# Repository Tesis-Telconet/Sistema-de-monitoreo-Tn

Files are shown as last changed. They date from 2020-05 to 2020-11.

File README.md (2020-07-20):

# Sistema-de-Monitoreo

Este repositorio contiene material diverso para poner en marcha un sistema de monitoreo de amenazas físicas (temperatura, humedad, voltajes, corrientes, calidad de gas). Los datos son recopilados por los distintos tipos de sensores instalados, el proceso de los datos y el envio de información es realizado por las placas Arduino UNO, la información es almacenada en una base de datos SQL. Los datos pueden ser visualizados en un sitio web, este sitio fue desarrollado usando la plantilla ADMIN LTE, para la comunicación entre los Arduinos y la base de datos y / o la base de datos y el sitio web, se desarrollo una APREST escrita en Python que utiliza el framework FLASK.  

El contenido se organiza del siguiente modo:

CASES: diseño delos cases para los Arduinos

Diagramas Proteus: Diagramas de conexión entre sensores y placas Arduino UNO

apirest2: Códigos para la creación de la APIREST y el desarrollo del sitio WEB

codigos finales: Códigos para las placas Arduinos UNO

Planos: Imágenes de las áreas donde se instaló el sistema y el plano del sistema en las instalaciones de Telconet

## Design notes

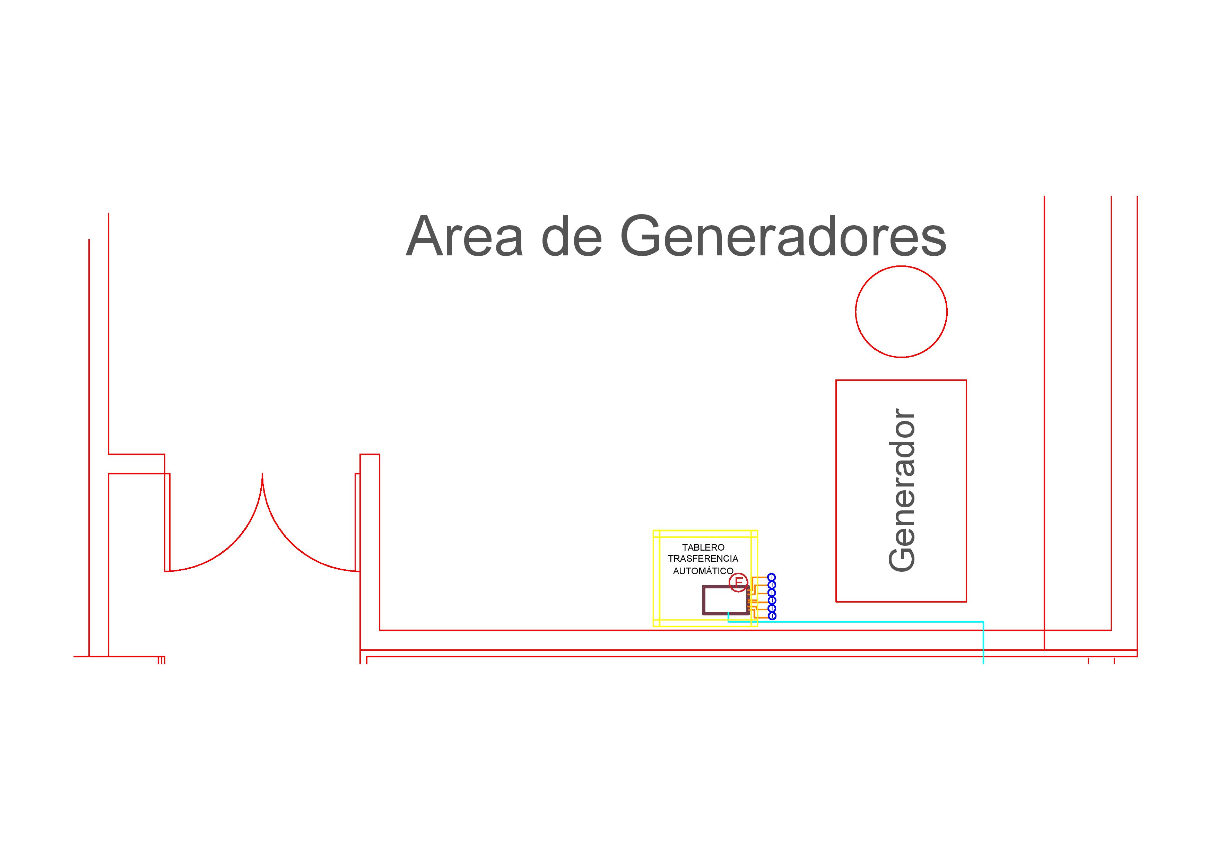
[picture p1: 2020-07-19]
planos/Plano Area Generador.jpg

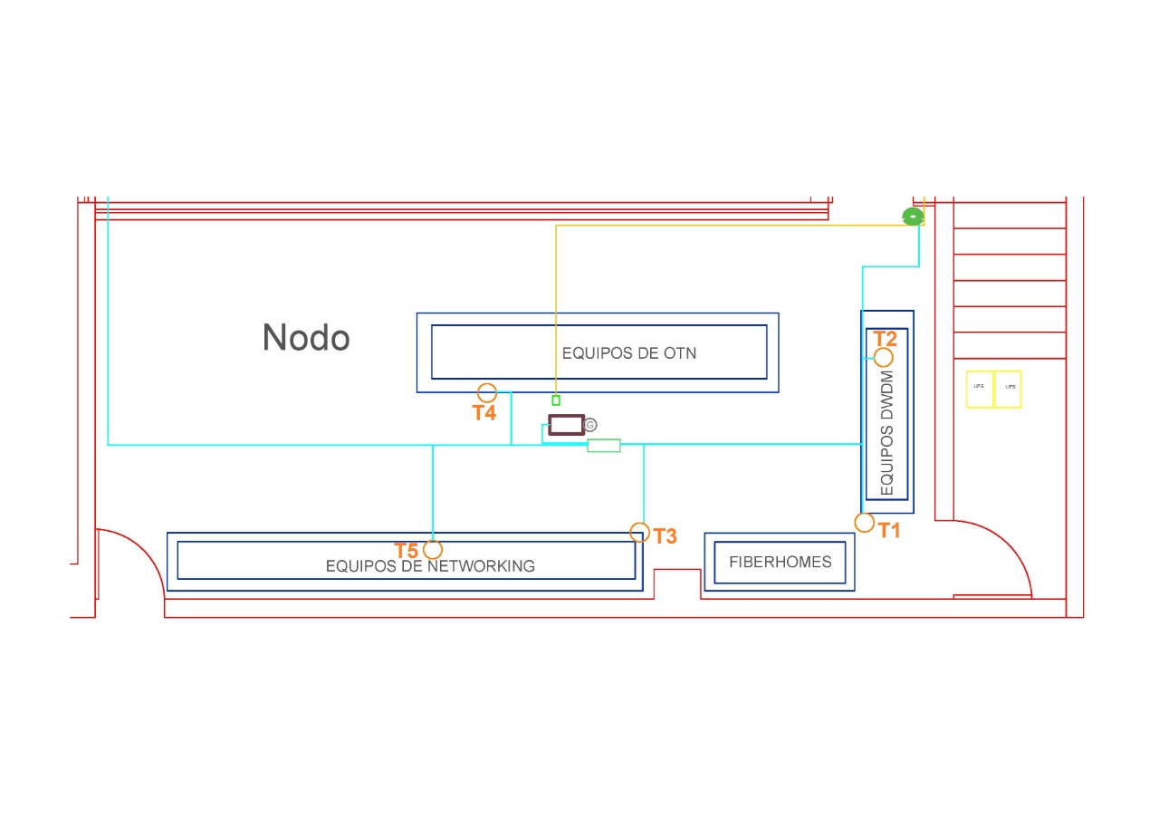
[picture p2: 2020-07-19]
planos/Plano nodo gosseal.jpeg

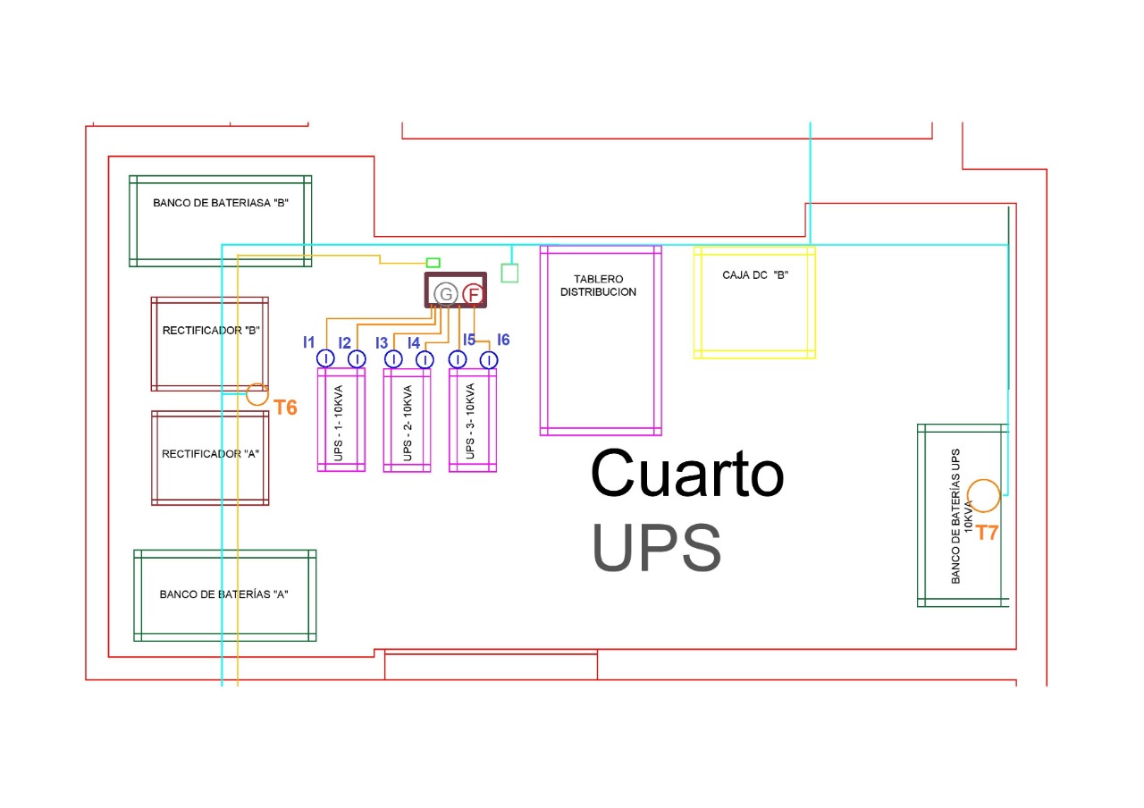
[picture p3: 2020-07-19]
planos/Plano cuarto de ups.jpeg

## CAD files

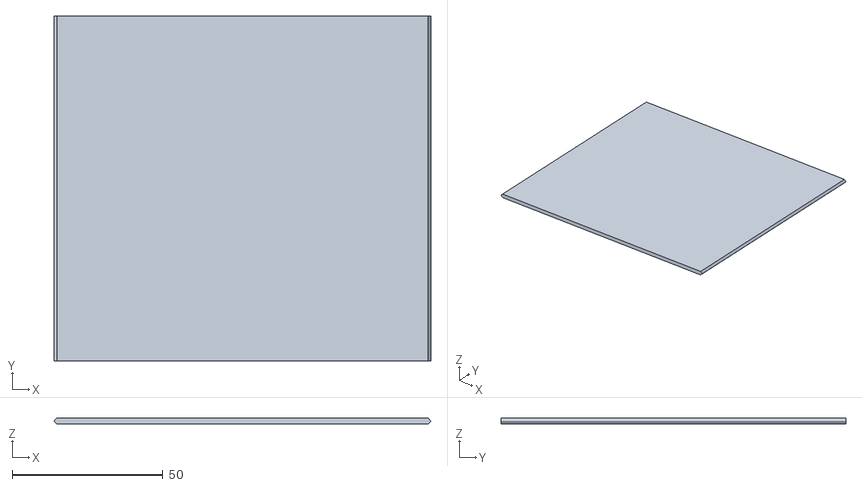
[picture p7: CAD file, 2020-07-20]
CASES/TAPA CASE GENERADOR F (1).stl
125.2 x 114.5 x 2.00

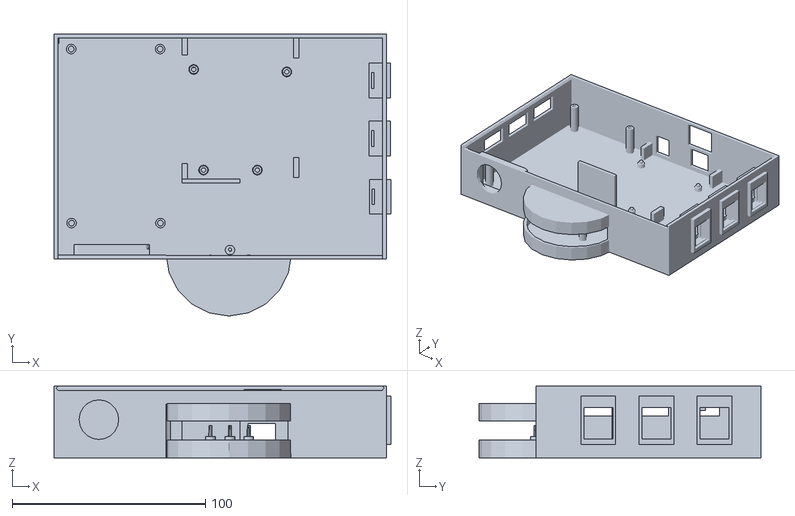
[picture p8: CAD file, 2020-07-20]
CASES/CASE CUARTO UPS F (1).stl
174.4 x 146.0 x 37.0

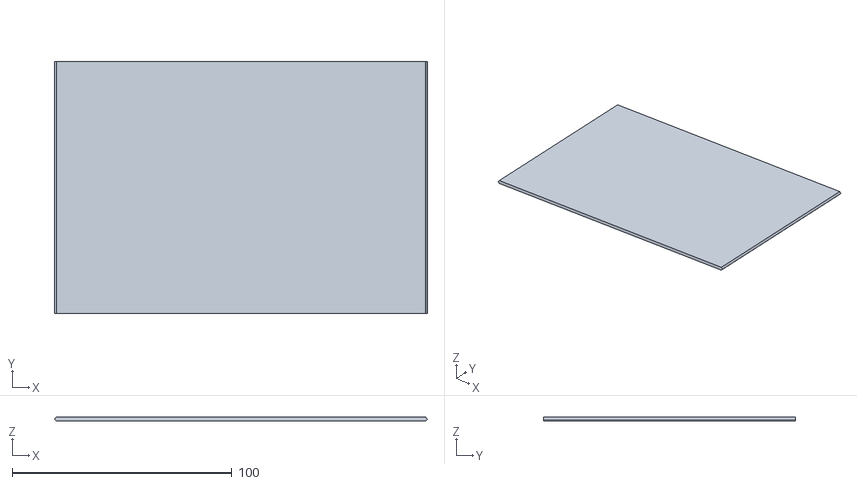
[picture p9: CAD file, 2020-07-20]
CASES/TAPA CASE CUARTO UPS (1).stl
169.8 x 114.5 x 2.00

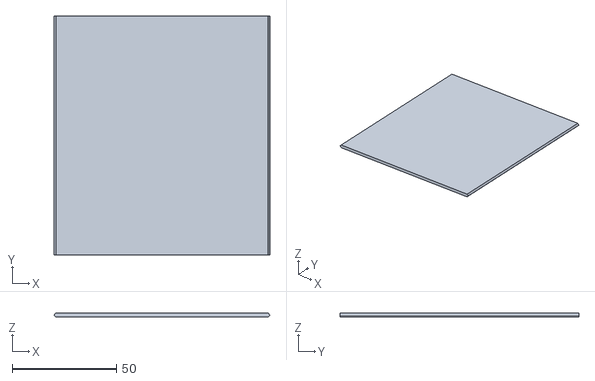
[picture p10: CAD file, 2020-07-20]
CASES/TAPA CASE NODO TELEPUERTO (1).stl
103.7 x 114.5 x 2.00

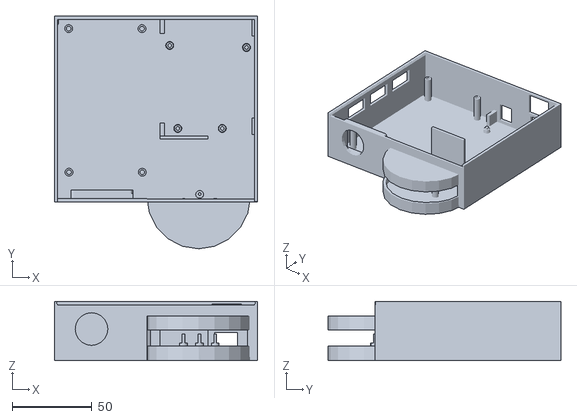
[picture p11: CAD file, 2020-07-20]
CASES/CASE GENERADOR F (1).stl
127.4 x 146.0 x 37.0

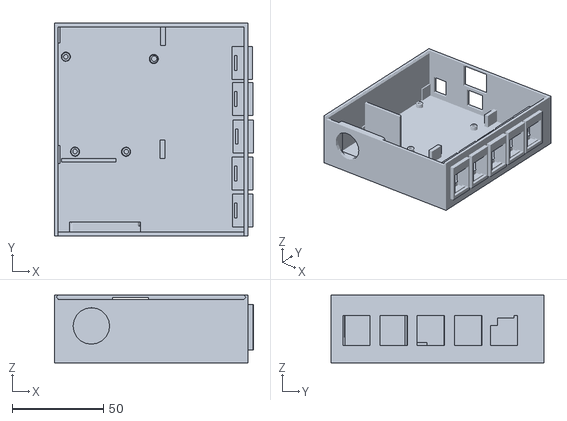
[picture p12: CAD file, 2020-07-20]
CASES/CASE NODO TELEPUERTO (1).stl
109.0 x 116.5 x 37.0

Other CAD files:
apirest2/GossealMonitoreo.dwg
planos/GossealMonitoreo.dwg

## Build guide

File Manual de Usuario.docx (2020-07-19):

Manual de Usuario

COMPONENTES:

El sistema está por compuesto de los siguientes componentes:

- Sensores de temperatura y humedad (DHT22)
- Sensores de gas (MQ2)
- Sensores de flama 5 canales
- Sensores de corriente (SCT)
- Arduinos UNO
- Raspberry Pi 3B+
- Switch Ethernet

FUNCIONAMIENTO:

Cuando el usuario desea iniciar el sistema, debe realizar los siguientes pasos:

1. Encender el servidor (Raspberry Pi) y ponerlo a funcionar.
2. Abrir un terminal en la pantalla de la Raspberry Pi.
3. Iniciar el servidor, para esto se debe digitar las siguientes líneas de comando en el terminal:
- cd Desktop/ Tesis
- source venv/bin/activate
- python3 api.py
4. Antes de digitar la última línea se debe crear la base de datos, para esto se debe digitar las siguientes líneas de comando en el terminal:
- Python3
- from app import db
- from sensor import Temperatura
- from sensor import Humedad
- from sensor import Corriente
- from sensor import Voltaje
- from sensor import Gas
- from sensor import Log
- db.create_all()
- exit()
5. Posterior a esto, se debe encender los 3 Arduinos.
6. Por último, encender los sensores.
7. Para que el sistema comience a enviar datos se debe presionar por 5 segundos el botón ubicado a lado derecho del arduino ubicado en el área del generador. El primer Arduino en enviar datos es el que está ubicado en el área del generador, luego lo hará el que está ubicado en el nodo y finalmente el que está ubicado en el nodo. Este orden se seguirá constantemente por el tiempo que desee el usuario.

NOTA: Este proceso se debe hacer siempre y cuando se haya apagado todo el sistema, en caso de que por situación fortuita uno o varios Arduinos se apaguen , el proceso debe realizarse desde el punto 5.

INICIO DEL SERVIDOR:

Una vez encendida la Raspberry Pi, se debe abrir un terminal y dirigirse a la ubicación del directorio del proyecto. Una vez en el directorio, se debe activar el entorno virtual y poner en funcionamiento el servidor (figura B.1).

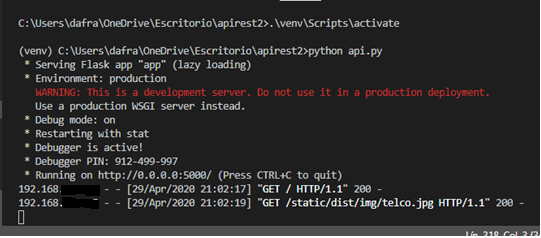
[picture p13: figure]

Figura B.1: Inicio del servidor

MONITOREO:

Para realizar el monitoreo de valores, que constituye el objetivo del proyecto, es necesario que el usuario utilice cualquier dispositivo con conexión a la red, estos dispositivos pueden ser un computador, laptop, smartphone.

Utilizando cualquiera de los dispositivos antes mencionados, se debe ingresar a la dirección del servidor 192.168.254.240 por medio de cualquier navegador web, de preferencia Mozilla Firefox o Google Chrome. Una vez en la página que muestra el navegador, se debe ingresar un nombre de usuario y una contraseña (figura B.2).

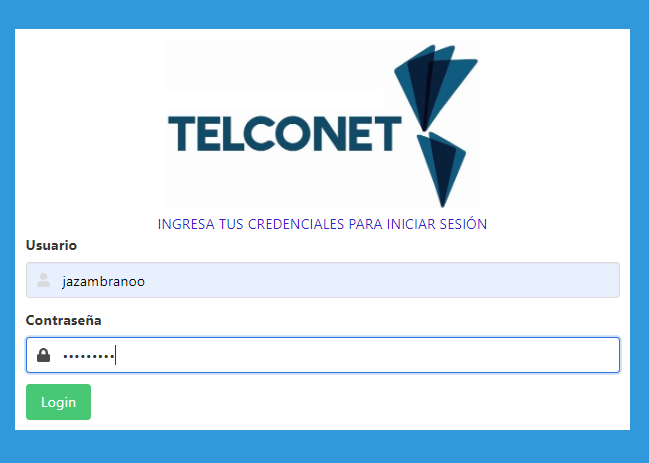
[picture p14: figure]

Figura B.2: Página de inicio de sesión

Se direccionará a la página de bienvenida (figura B3). En esta página el usuario puede escoger el tipo de información que desea visualizar.

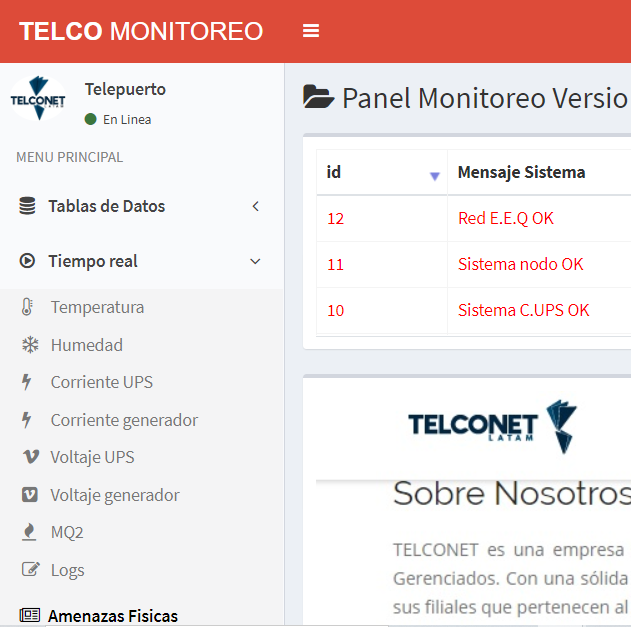
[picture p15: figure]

Figura B.3: Página de bienvenida

Dentro de cualquier página que muestre la información de los sensores en tablas (figura B.4) se tiene varias opciones. Además, en la tabla B.1 se muestra detalles de cada icono.

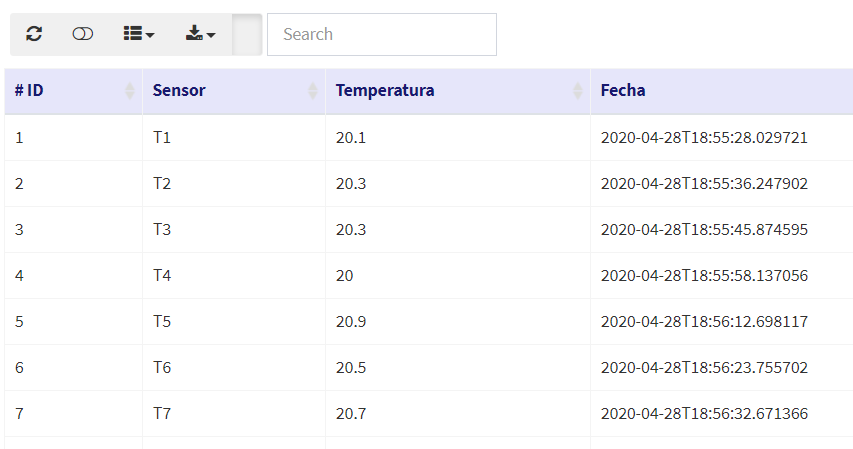
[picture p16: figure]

Figura B.4: Tablas en página web

Tabla B.1: Íconos de opción para tablas

BOTÓN | APLICACIÓN
| Esta opción permite actualizar la información de la tabla.
| Esta opción permite seleccionar qué columnas mostrar.
| Esta opción permite exportar los datos en hojas de cálculo o en archivo pdf.
| Esta opción permite actualizar la información de la tabla.

Dentro de cualquier página que muestre la información de los sensores en gráficos en tiempo real (figura B.5), se tiene varias opciones.

Vista: View in full screen, permite contemplar el gráfico en toda la pantalla.

Impresión: Print Chart, permite imprimir el gráfico.

Exportar: Download, permite exportar el gráfico en formatos: PNG, JPEG, PDF, SVG.

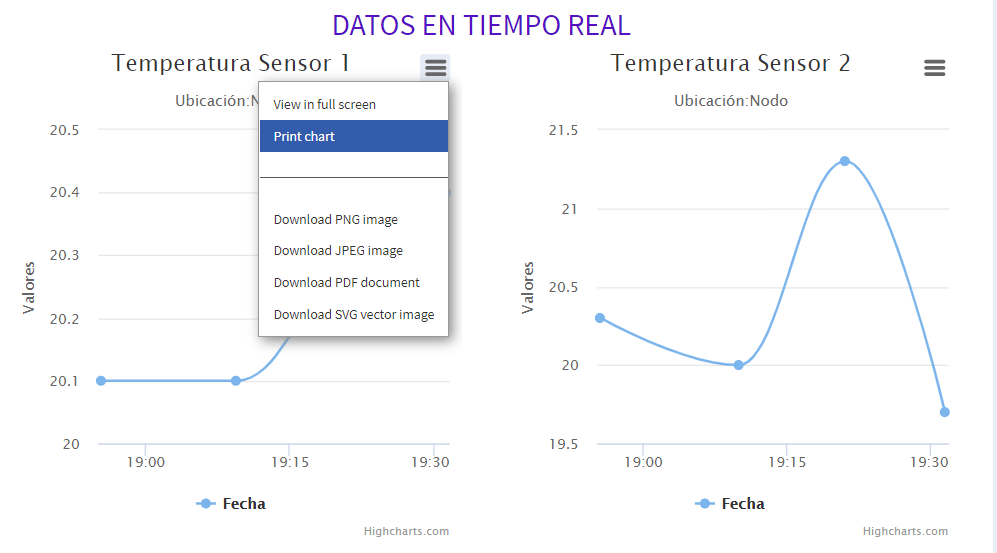
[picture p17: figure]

Figura B.5: Gráficos en página web

Una sección importante que está presente en todas las páginas del sitio web, es la tabla de mensajes del sistema ubicada en la parte superior de la página web (Figura B.6). Esta tabla funciona como un elemento de alerta.

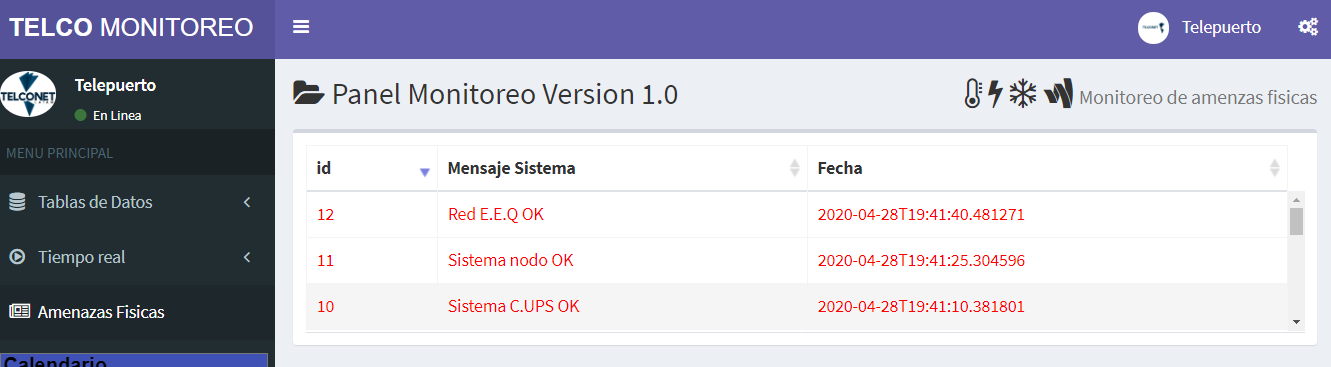
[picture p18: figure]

Figura B.6: Tabla de mensajes del sistema

ERRORES:

Todos los componentes están energizados desde los UPSs, pero puede producirse algún evento fortuito que altere el funcionamiento del sistema. En la tabla B.2 se detalla los errores comunes que suelen presentarse y las posibles soluciones a cada de uno de ellos:

Tabla B.2: Errores de funcionamiento

ERROR | SOLUCIÓN
No se puede acceder a la página web | Solicitar las credenciales al administrador del nodo.
La página web no puede ser visualizada | - Verificar que la Raspberry PI esté encendida. - Verificar que el servidor esté ejecutándose.
La página web no muestra ningún dato | - Verificar que la API esté recibiendo peticiones POST y GET. - Verificar que el switch este encendido. - Verificar la conexión de los cables de red. - Reiniciar el servidor.
La página web dejó de actualizar las tablas y gráficos | - Verificar que el o los Arduinos estén encendidos. - Verificar que el switch esté encendido. - Verificar la conexión de los cables de red. - Verificar la conexión de los sensores. - Verificar el o los Arduinos por el monitor serie. - Reiniciar el o los Arduinos. - Subir nuevamente los códigos.
La página web muestra solo algunos datos | - Verificar que el o los Arduinos estén encendidos. - Verificar la conexión de los sensores. - Reemplazar sensor.

MANTENIMIENTO:

Se debe realizar una limpieza de los componentes una vez cada dos meses, preferible en horario de la noche. Para la limpieza se necesita contar con los siguientes elementos.

- Aire comprimido
- Brocha pequeña
- Destornilladores
- Multímetro

En el caso de no ser un mantenimiento programado, se procederá a realizar la limpieza de los cases que alojan los Arduinos del exceso de polvo y suciedad, aplicando aire comprimido directamente a ellos.

Los pasos para un mantenimiento programado son los siguientes:

- Antes de apagar el servidor, realizar una copia de la base de datos.
- Apagar todos los dispositivos del sistema.
- Desconectar todos los cables de los diferentes componentes conectados ya sea a los Arduinos o a la Raspberry Pi.
- Desarmar los cases de los Arduinos y Raspberry Pi.
- Aplicar aire comprimido sobre los periféricos de la Raspberry Pi, Arduinos y sensores.
- Con una brocha pequeña se debe limpiar todos los cases.
- Con el multímetro, verificar la continuidad entre los cables que sirven para la conexión de los sensores, remplazarlos en caso de encontrarlos defectuosos.
- Armar nuevamente todo el sistema.
- Encender todos los dispositivos.
- Iniciar el servidor.

REMPLAZO DE COMPONENTES:

Todos los componentes del sistema, al ser dispositivos electrónicos, tienen una vida que se puede acortar dependiendo de muchos factores.

- Para remplazar un sensor DHT, no es necesario apagar el sistema, ni realizar ninguna desconexión, solo se debe reemplazar el sensor ya que el cable de conexión cuenta con terminales de conexión tipo hembra.
- Para reemplazar un sensor MQ2 o de flama, se debe apagar el Arduino debido a que estos sensores están ubicados en el case del Arduino. Una vez apagado el Arduino, se debe reemplazar el o los sensores averiados. La única desconexión que se debe hacer es la de los cables con terminación tipo hembra que van a estos sensores.
- Para reemplazar un sensor de corriente, no es necesario apagar el Arduino, pero por motivos de seguridad es recomendable hacerlo. Una vez apagado el Arduino, con la ayuda de un destornillador plano pequeño, se debe aflojar el cable de conexión de la bornera.
- Cuando por motivos de fuerza mayor el elemento a remplazar sea un Arduino, se debe volver a cargar el código, realizar todas las conexiones y volverlo a encender. El mismo proceso se debe realizar en el caso de que el dispositivo averiado sea la Raspberry Pi.

COPIA DE INFROMACION DE LA BASE DE DATOS:

Se recomienda realizar una copia de la base de datos cada 15 días, esto con el fin de evitar que el sitio web colapse por la cantidad de información almacenada en la bd. Para realizar la copia de la base de datos se debe realizar los siguientes pasos:

1. Detener el servidor, para esto se deben ejecutar las siguientes líneas de comando:
- En la terminal que esta abierta se debe presionar CONTROL + C
- Apagar todos los Arduinos.
- En la carpeta ubicada en el escritorio con el nombre de Tesis, se encuentra un archivo llamado db.sqlite, se le debe dar click derecho y cortar a una nueva ubicación y/o dispositivo usb.
- Luego de esto se debe crear la base de datos e iniciar el servidor, para lo cual se debe realizar todos los pasos a partir el paso 3 descritos en la sección de funcionamiento.

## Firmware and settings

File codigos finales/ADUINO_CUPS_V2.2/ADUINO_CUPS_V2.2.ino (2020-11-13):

/////LIBRERIAS////////////////////////////
#include <Ethernet.h>++++++++++,,+
#include <SPI.h>
#include "DHT.h"
#include <ArduinoJson.h>
#include "RestClient.h"
#include <SoftwareSerial.h>

int data = 0; //Serial Data
int data2 = 0; //RX TX Data
SoftwareSerial mySerial(8, 9); // RX, TX

///////ASIGNACION DE PINES PARA LOS SENSORES////////////////////////////
#define DHT1PIN 7
#define DHT2PIN 6

///////DEFINIR EL TIPO DE SENSOR DHT////////////////////////////
#define DHT1TYPE DHT22
#define DHT2TYPE DHT22


DHT dht1(DHT1PIN, DHT1TYPE);
DHT dht2(DHT2PIN, DHT2TYPE);


///////PARAMETROS PARA ENVIAR DATOS A LA APIREST////////////////////////////
#define IP "192.168.254.240" // Server IP
#define PORT 5000     // Server Port
RestClient client = RestClient(IP, PORT);

#include <avr/wdt.h>
void softwareReset( uint8_t prescaller) {    // iniciar el perro guardián con el prescaller proporcionado
  wdt_enable( prescaller);                   // espere a que expire el tiempo de prescaller sin enviar la señal de reinicio usando el método wdt_reset ()
  while (1) {}}


void setup() {
  while (!Serial) {
    ; // Espere a que se conecte el puerto serie. Necesario solo para puerto USB nativo
  }
  Serial.begin(9600);
  mySerial.begin(4800);
  pinMode(2, INPUT_PULLUP);
  pinMode(3, INPUT_PULLUP);
  analogReference(INTERNAL);
//  Serial.println("connect to network");
  dht1.begin();
  dht2.begin();
  byte mac[] = { 0xDE, 0xAD, 0xBE, 0xEF, 0xFE, 0xED };
  byte ip[] = { 192, 168, 254, 246 };
  Ethernet.begin(mac, ip);
}

///////DECLARACIÓN DE VARIABLES////////////////////////////
String texto;
String response;
String login;

void loop()
{
 //Serial.println("iniciando");
//  if (Serial.available() > 0) {
//    data = Serial.parseInt();
//    if (data == 1) {
//      goto a;}
//  }
  
  if (mySerial.available() > 0) {
    data2 = mySerial.read();
    if (data2 == 1) {
a:
      delay(5000);
      int sensorfire = digitalRead(3);
      if (sensorfire == HIGH) {
        texto = "Fuego C.UPS";
        http_POST_log(texto);
      }
      delay(5000);
      int sensorhmo = digitalRead(2);
      if (sensorhmo == LOW) {
        texto = "Smoke Alarm U";
        http_POST_log(texto);
      }
      delay(5000);
      float t6 = dht1.readTemperature();
      login = "T6";
      http_POST_sensor(t6, "temperature", "/SensorData/temperatura");

      delay(5000);
      float h6 = dht1.readHumidity();
      login.replace("T6", "H6");
      http_POST_sensor(h6, "humidity",  "/SensorData/humedad");

      delay(5000);
      float t7 = dht2.readTemperature();
      login.replace("H6", "T7" );
      http_POST_sensor(t7, "temperature", "/SensorData/temperatura");

      delay(5000);
      float h7 = dht2.readHumidity();
      login.replace("T7", "H7");
      http_POST_sensor(h7, "humidity",  "/SensorData/humedad");
      
      
      ///// VERIFICACIÓN DE VALORES//////
    
      delay(5000);
      if (isnan(h6) || isnan(t7) )                                       //Comprobamos si ha habido algún error en la lectura
      { texto = "Error sensores C-UPS";
        http_POST_log(texto);
      //return;
      }
      else {
        delay(5000); 
        texto = "Sensores C-UPS OK";
        http_POST_log(texto);
           
       // if ( t6 >= 25 ||t7 >= 25    )
      //{ texto = "Temperatura alta: C-UPS"; //si la temperaura esta fuera del rango, nos envia un mensaje
       // http_POST_log(texto);}  
      }



   
      delay(5000);
      float pin = A0;
      float I1 = get_corriente(pin); //Corriente eficaz (A)
      login.replace("H7", "U1-L1");
      http_POST_sensor(I1, "corriente",  "/SensorData/corriente");
      

      delay(5000);
      float pin1 = A1;
      float I2 = get_corriente(pin1); //Corriente eficaz (A)
      login.replace("U1-L1", "U1-L2");
      http_POST_sensor(I2, "corriente",  "/SensorData/corriente");
      

      delay(5000);
        if (I1 < 1 ||I2 < 1  )                                        //Comprobamos si ha habido algún error en la lectura
      { texto = " UPS1 off";
        http_POST_log(texto);
        delay(5000);
      }

      float pin2 = A2;
      float I3 = get_corriente(pin2); //Corriente eficaz (A)
      login.replace("U1-L2", "U2-L1");
      http_POST_sensor(I3, "corriente",  "/SensorData/corriente");
      

      delay(5000);
      float pin3 = A3;
      float I4 = get_corriente(pin3); //Corriente eficaz (A)
      login.replace("U2-L1", "U2-L2");
      http_POST_sensor(I4, "corriente",  "/SensorData/corriente");
       

         delay(5000);
         if (I3 < 1 ||I4 < 1  )                                        //Comprobamos si ha habido algún error en la lectura
      { texto = "UPS2 off";
        http_POST_log(texto);
        delay(5000);//return;
      }

      
      float pin4 = A4;
      float I5 = get_corriente(pin4); //Corriente eficaz (A)
      login.replace("U2-L2", "U3-L1");
      http_POST_sensor(I5, "corriente",  "/SensorData/corriente");
;

      delay(5000);
      float pin5 = A5;
      float I6 = get_corriente(pin5); //Corriente eficaz (A)
      login.replace("U3-L1", "U3-L2");
      http_POST_sensor(I6, "corriente",  "/SensorData/corriente");
 ;
     
            delay(5000);
          if (I5 < 0.8 ||I6 < 1  )                                        //Comprobamos si ha habido algún error en la lectura
      { texto = "UPS3 off";
        http_POST_log(texto);
        delay(5000);//return;
      }
       
      



      texto = "";
      response = "";
      login = "";
      mySerial.write(1);
      Serial.println("Envio de dato");
      delay(1000);
      mySerial.write(1);
      softwareReset( WDTO_4S);
    }
    }
  delay(1000);
}


///////FUNCIONES////////////////////////////////////////////////////////

int http_POST_sensor(float sensor, String tag , const char* dir_recurso) {
  response = "";
  client.setHeader("Authorization: Basic cmljdmVhbDoxMjM0==");
  client.setHeader("Content-Type: application/json");
  StaticJsonBuffer<200> jsonBuffer;
  char json[256];
  JsonObject& root = jsonBuffer.createObject();
  root[tag] = sensor;
  root["login"] = login;
  root.printTo(json, sizeof(json));
  //Serial.println(json);
  int statusCode = client.post(dir_recurso, json, &response);
  //Serial.print("Status code from server: ");
  //Serial.println(statusCode);
  //Serial.print("Response body from server: ");
  //Serial.println(response);
  //return statusCode;
  delay(5000);
}


int http_POST_log(String texto) {
  String response = "";
  client.setHeader("Authorization: Basic cmljdmVhbDoxMjM0==");
  client.setHeader("Content-Type: application/json");
  const size_t bufferSize = JSON_OBJECT_SIZE(1);
  DynamicJsonBuffer jsonBuffer(bufferSize);
  JsonObject& root = jsonBuffer.createObject();
  root["log"] = texto;
  root.printTo(Serial);
  char json[270];
  root.printTo(json, sizeof(json));
  int statusCode = client.post("/SensorData/log", json, &response);
  //Serial.print("Status code from server: ");
  //Serial.println(statusCode);
  //Serial.print("Response body from server: ");
  //Serial.println(response);
  //return statusCode;
  delay(5000);
}

float get_corriente(float pin)
{
  float voltajeSensor;
  float corriente = 0;
  float Sumatoria = 0;
  long tiempo = millis();
  int N = 0;
  while (millis() - tiempo < 500) //Duración 0.5 segundos(Aprox. 30 ciclos de 60Hz)
  {
    voltajeSensor = analogRead(pin) * (1.1 / 1024.0);////voltaje del sensor
    corriente = voltajeSensor * 100.0; //corriente=VoltajeSensor*(30A/1V)
    Sumatoria = Sumatoria + sq(corriente); //Sumatoria de Cuadrados
    N = N + 1;
    delay(1);
  }
  Sumatoria = Sumatoria * 2; //Para compensar los cuadrados de los semiciclos negativos.
  corriente = sqrt((Sumatoria) / N); //ecuación del RMS
  return (corriente);
}

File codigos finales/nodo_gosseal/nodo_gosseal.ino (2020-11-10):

/////LIBRERIAS////////////////////////////
#include <Ethernet.h>
#include <SPI.h>
#include "DHT.h"
#include <ArduinoJson.h>
#include "RestClient.h"
#include <SoftwareSerial.h>

int sensorfire = 0;
int sensorpuerta= 0;
int data = 0; //Serial Data
int data2 = 0; //RX TX Data
SoftwareSerial mySerial(A4, A5); // RX, TX

///////ASIGNACION DE PINES PARA LOS SENSORES////////////////////////////
#define GAS_PIN A0
#define DHT1PIN 3
#define DHT2PIN 5
#define DHT3PIN 6
#define DHT4PIN 7
#define DHT5PIN 8

///////DEFINIR EL TIPO DE SENSOR DHT////////////////////////////
#define DHT1TYPE DHT22
#define DHT2TYPE DHT22
#define DHT3TYPE DHT22
#define DHT4TYPE DHT22
#define DHT5TYPE DHT22

DHT dht1(DHT1PIN, DHT1TYPE);
DHT dht2(DHT2PIN, DHT2TYPE);
DHT dht3(DHT3PIN, DHT3TYPE);
DHT dht4(DHT4PIN, DHT4TYPE);
DHT dht5(DHT5PIN, DHT5TYPE);


///////PARAMETROS PARA ENVIAR DATOS A LA APIREST////////////////////////////
#define IP "192.168.254.240" // Server IP
#define PORT 5000     // Server Port
RestClient client = RestClient(IP, PORT);

#include <avr/wdt.h>

void softwareReset( uint8_t prescaller) {
  // start watchdog with the provided prescaller
  wdt_enable( prescaller);
  // wait for the prescaller time to expire
  // without sending the reset signal by using
  // the wdt_reset() method
  while (1) {}
}


void setup() {
  while (!Serial) {
    ; // Espere a que se conecte el puerto serie. Necesario solo para puerto USB nativo
  }
  Serial.begin(9600);
  mySerial.begin(4800);
  pinMode(2, INPUT_PULLUP);
  //pinMode(3, INPUT_PULLUP);
 
  Serial.println("conectado");
  dht1.begin();
  dht2.begin();
  dht3.begin();
  dht4.begin();
  dht5.begin();
  byte mac[] = { 0xDE, 0xAD, 0xBE, 0xEF, 0xFE, 0xED };
  byte ip[] = { 192, 168, 254, 242 };
  Ethernet.begin(mac, ip);
}
///////DECLARACIÓN DE VARIABLES////////////////////////////
String texto;
String response;
String login;


void loop()
{

  //Serial.println("iniciando");
  
  
  if (mySerial.available() > 0) {
    data2 = mySerial.read();
    if (data2 == 1) {
a:

      //sensorfire = digitalRead(3);
      //if (sensorfire == HIGH) {
       // texto = "Fuego Detectado";
        //http_POST_log(texto);
      //}

      sensorpuerta = digitalRead(2);
      if (sensorpuerta == HIGH) {
        texto = "Puerta Abierta";
        http_POST_log(texto);
      }
      delay(5000);
      float t1 = dht1.readTemperature();
      login = "T1";
      http_POST_sensor(t1, "temperature", "/SensorData/temperatura");

      delay(5000);
      float h1 = dht1.readHumidity();
      login.replace("T1", "H1");
      http_POST_sensor(h1, "humidity",  "/SensorData/humedad");

      delay(5000);
      float t2 = dht2.readTemperature();
      login.replace("H1", "T2" );
      http_POST_sensor(t2, "temperature", "/SensorData/temperatura");

      delay(5000);
      float h2 = dht2.readHumidity();
      login.replace("T2", "H2");
      http_POST_sensor(h2, "humidity",  "/SensorData/humedad");

      delay(5000);
      float t3 = dht3.readTemperature();
      login.replace("H2", "T3" );
      http_POST_sensor(t3, "temperature", "/SensorData/temperatura");

      delay(5000);
      float h3 = dht3.readHumidity();
      login.replace("T3", "H3");
      http_POST_sensor(h3, "humidity",  "/SensorData/humedad");

      delay(5000);
      float t4 = dht4.readTemperature();
      login.replace("H3", "T4" );
      http_POST_sensor(t4, "temperature", "/SensorData/temperatura");
      
      delay(5000);
      float h4 = dht4.readHumidity();
      login.replace("T4", "H4");
      http_POST_sensor(h4, "humidity",  "/SensorData/humedad"); 

      delay(5000);
      float t5 = dht5.readTemperature();
      login.replace("H4", "T5" );
      http_POST_sensor(t5, "temperature", "/SensorData/temperatura");

      delay(5000);
      float h5 = dht5.readHumidity();
      login.replace("T5", "H5");
      http_POST_sensor(h5, "humidity",  "/SensorData/humedad");
   

      delay(5000);
      float g1  = analogRead(A0);
      login.replace("H5", "MQ1");
      http_POST_sensor(g1, "cant_gas",  "/SensorData/gas");
      if ( g1 > 100 )                                   //establecemos el rango de temperatura
      { texto = "Presencia Humo"; //si la temperaura esta fuera del rango, nos envia un mensaje
        http_POST_log(texto);
      }
      
      delay(5000);
       if ( t1 >= 21 ||t2 >= 21 ||t3 >= 21 ||t4 >= 21 ||t4 >= 21   )
      { texto = "Temperatura alta:Nodo"; //si la temperaura esta fuera del rango, nos envia un mensaje
        http_POST_log(texto);
      }

      delay(5000);
       if ( t1 <= 15 ||t2 <= 15 ||t3 <= 15 ||t4 <= 15 || t5 <= 15   )
      { texto = "Temperatura baja:Nodo"; //si la temperaura esta fuera del rango, nos envia un mensaje
        http_POST_log(texto);
      }

      delay(5000);
      if (isnan(h1) || isnan(t2) || isnan(h3) || isnan(t4)|| isnan(t5)  )                                     //Comprobamos si ha habido algún error en la lectura
      { texto = "Error lectura sensores Nodo";
        http_POST_log(texto);
        //return;
      }
      else {
        texto = "Sistema Nodo OK";
        http_POST_log(texto);
      }
      

      texto = "";
      response = "";
      login = "";
      mySerial.write(1);
      Serial.println("Envio");
      delay(1000);
      mySerial.write(2);
      delay(1000);
      softwareReset( WDTO_4S);
    }

  }
  delay(1000);
}


///////FUNCIONES////////////////////////////////////////////////////////

int http_POST_sensor(float sensor, String tag , const char* dir_recurso) {
  response = "";
  client.setHeader("Authorization: Basic cmljdmVhbDoxMjM0==");
  client.setHeader("Content-Type: application/json");
  StaticJsonBuffer<200> jsonBuffer;
  char json[256];
  JsonObject& root = jsonBuffer.createObject();
  root[tag] = sensor;
  root["login"] = login;
  root.printTo(json, sizeof(json));
  Serial.println(json);
  int statusCode = client.post(dir_recurso, json, &response);
  //Serial.print("Status code from server: ");
  //Serial.println(statusCode);
  //Serial.print("Response body from server: ");
  //Serial.println(response);
  //return statusCode;
  delay(5000);
}


int http_POST_log(String texto) {
  String response = "";
  client.setHeader("Authorization: Basic cmljdmVhbDoxMjM0==");
  client.setHeader("Content-Type: application/json");
  const size_t bufferSize = JSON_OBJECT_SIZE(1);
  DynamicJsonBuffer jsonBuffer(bufferSize);
  JsonObject& root = jsonBuffer.createObject();
  root["log"] = texto;
  root.printTo(Serial);
  char json[270];
  root.printTo(json, sizeof(json));
  int statusCode = client.post("/SensorData/log", json, &response);
  //Serial.print("Status code from server: ");
  //Serial.println(statusCode);
  //Serial.print("Response body from server: ");
  //Serial.println(response);
  //return statusCode;
  delay(5000);
}

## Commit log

2020-07-19 Create README.md
    Este repositorio contiene material diverso, tutoriales y ejemplos de código ... principalmente ejemplos en el lenguaje de programación Ruby .
    El contenido se organiza del siguiente modo:
    Carpeta Contenido
    iloveruby Ejemplos y miniproyectos realizados con Ruby
    charlas Charlas sobre diversos temas
    comparativa Análisis comparativo de Ruby con otros idiomas de programación
2020-07-19 Create README.md
    -----------------------------------------------------------------------------------------------------------------------------------
    CARPETA CONTENIDO
    -----------------------------------------------------------------------------------------------------------------------------------
    Diagramas Proteus Diagramas de conexión entre sensores y placas ArduinosCARPETA CONTENIDO
    Diagramas Proteus Diagramas de conexión entre sensores y placas Arduinos
    apirest2 Códigos para la creación de la APIREST y el desarrollo del sitio WEB
    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
